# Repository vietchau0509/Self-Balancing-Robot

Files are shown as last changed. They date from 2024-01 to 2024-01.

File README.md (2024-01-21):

# Self-Balancing-Robot
This project involves designing a 2-wheeled, self-balancing robot with capabilities for sensor integration. Using 3-axis accelerometers, gyros, and odometry, the robot maintains an upright position while allowing for IR remote-controlled movement.

Key Components

3D-Printed Robot Frame: Forms the robot's structural base.

Robot Wheels (2): Enable robot mobility.

Training Stand: Assists in testing and development.

Buna-N Nitrile O-Rings (2): Serve as mechanical buffers.

DC Gearhead Motors (2): Power the wheels.

Pan Head Screws (4): For component assembly.

DRV8833 Dual H-Bridge: Manages motor control.

MPU-6050 6-DOF IMU: Balancing and orientation data.

Optical Interrupters (2): Measure wheel rotation for odometry.

IR Sensor: Receives remote control signals.

Resistors (4): Limit current and provide pull-up for sensors.

Battery Holder: Contains batteries for power.

AA NiMH Batteries (4): Powers the robot without using alkaline batteries.

Double-Row Pin Headers (2): For component connections.

Single Pin Headers (2): For battery circuit connections.

Single-Row Socket Headers (2): Connects the motor driver.

Pitch Terminals (2): Facilitate wiring and connections.

Slide Switch: Manages battery circuit power.

Plastic-Thread Screws (6): Secures PCB and battery.

FR4 PC Board: Base for electronic components.

TM4C123G Eval Board: Central microcontroller.

IR Remote: Controls the robot remotely.

Dowel Rod: Structural element.

Top Weight: Balances and stabilizes the robot.

Development and Learning

This project demonstrates intricate hardware-software integration, offering a hands-on experience in robotic controls, sensor interfacing, and real-time system programming.

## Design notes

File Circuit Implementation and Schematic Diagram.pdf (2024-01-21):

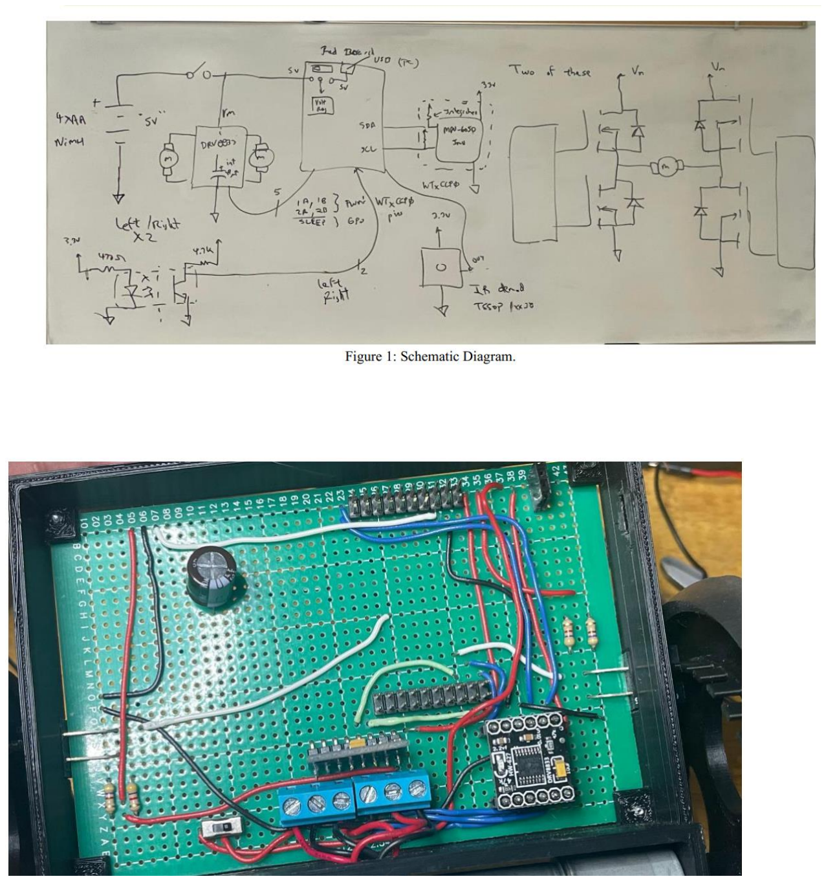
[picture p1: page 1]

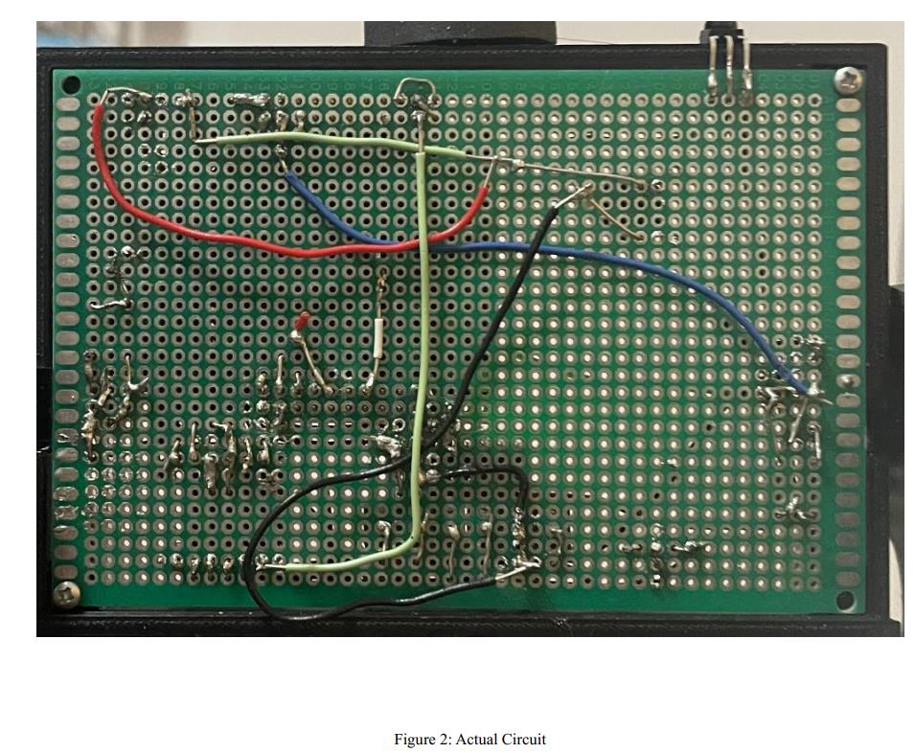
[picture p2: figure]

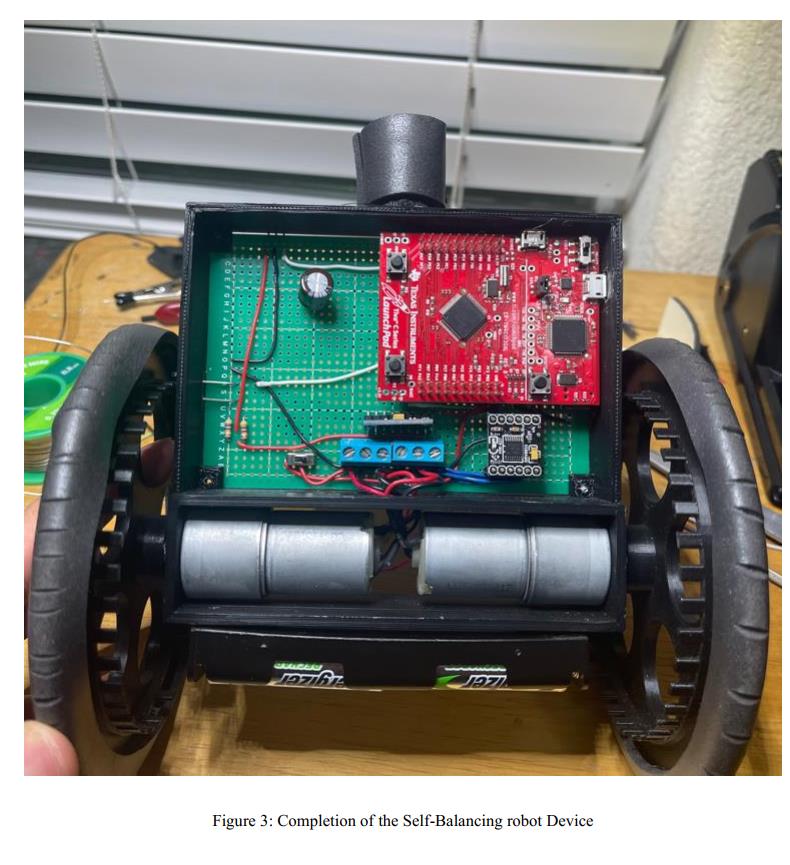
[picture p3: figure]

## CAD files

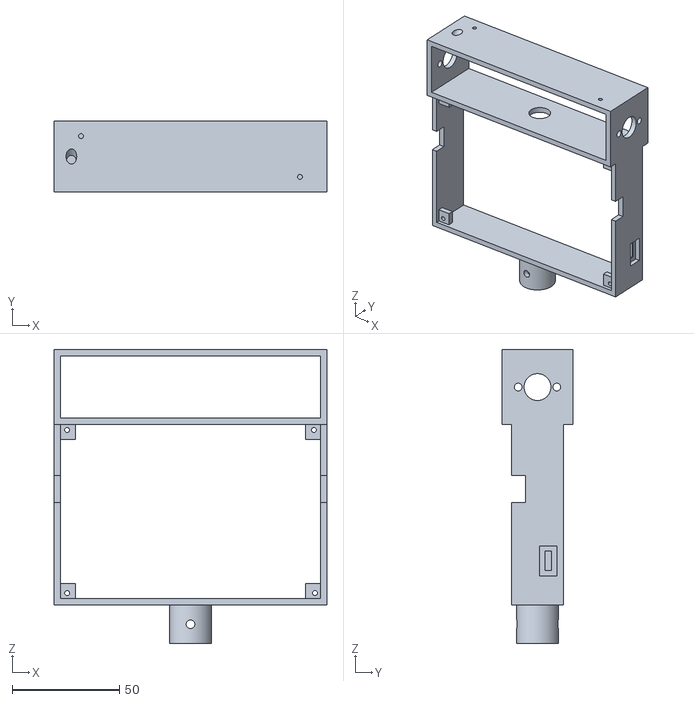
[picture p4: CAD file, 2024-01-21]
STL Files/2_wheel_robot_base.stl
127.0 x 33.0 x 137.0

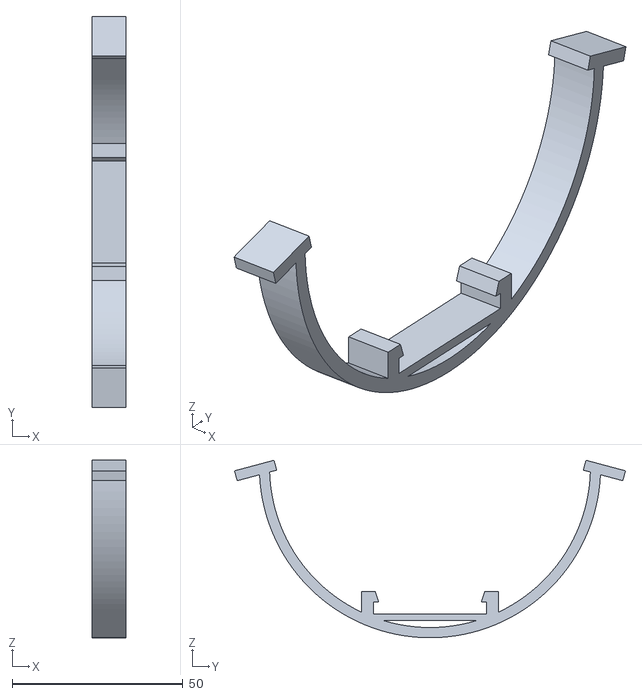
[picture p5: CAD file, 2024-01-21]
STL Files/stand.stl
10.0 x 114.6 x 52.0

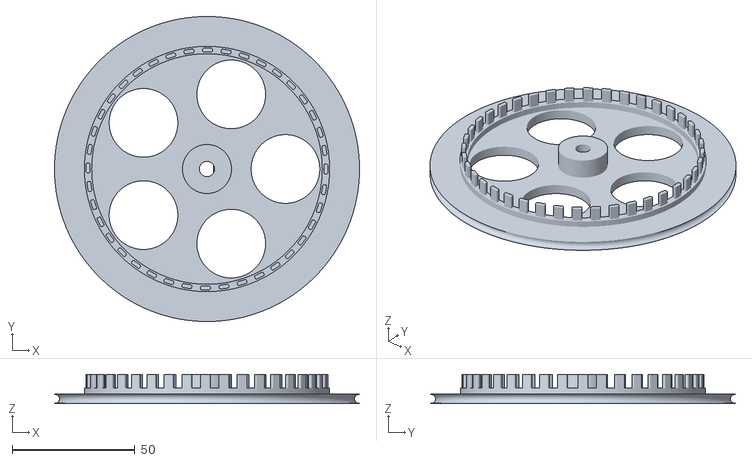
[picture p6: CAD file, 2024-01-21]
STL Files/125mm_wheel.stl
124.4 x 124.4 x 12.0

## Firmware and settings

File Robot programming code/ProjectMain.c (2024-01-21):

#include <stdint.h>
#include <stdbool.h>
#include <stdio.h>
#include <string.h>
#include "tm4c123gh6pm.h"
#include "gpio.h"
#include "clock.h"
#include "wait.h"
#include "nvic.h"
#include "uart0.h"
#include "motor_control.h"
#include "i2c0.h"
#include <math.h>  // for atan2 and sqrt
#include "eeprom.h"
#include <stdlib.h>


//IR Decoder PD0
//   PhA0 (PD6) and PhB0 (PD7) are connected to 256 cpr optical encoder
// Motor 0: PWM PA6, DIR PA7 --- OP sen PC7
// Motor 1: PWM PF2, DIR PF3 --- OP sen PC5

// Define the IR remote signals
const char RIGHT_ARROW[] =  "00100000110111110110000010011111";
const char LEFT_ARROW[] =   "00100000110111111110000000011111";
const char UP_ARROW[] =     "00100000110111110000001011111101";
const char DOWN_ARROW[] =   "00100000110111111000001001111101";
const char STOP[] =         "00100000110111110011111011000001";
#define SLEEP_PIN       PORTF, 1

#define IR_PIN          PORTD, 0
#define OP_PIN_PC5      PORTC, 5
#define OP_PIN_PC7      PORTC, 7



uint32_t targetinterruptCount_PC5 = 0;
uint32_t targetinterruptCount_PE2 = 0;
bool shouldStopMotors = false;
uint32_t OptTime0=0;
uint32_t OptTime1=0;
volatile uint32_t OptCount0=0;
volatile uint32_t OptCount1=0;
// Struct to represent the IR protocol parameters
typedef struct
{
    uint32_t InitTime;
    uint32_t Logic_0;
    uint32_t Logic_1;
    uint32_t Leniency;
} IRProtocol;

// Enum to represent the different buttons on the remote
typedef enum
{
    BUTTON_RIGHT_ARROW,
    BUTTON_LEFT_ARROW,
    BUTTON_UP_ARROW,
    BUTTON_DOWN_ARROW,
    BUTTON_STOP,
    BUTTON_UNKNOWN,

} RemoteButton;

// Struct to represent the IR signal data
typedef struct
{
    char data[33]; // 33 to include null terminator
    uint32_t count;
    bool ReceivingBit_Flag;
    RemoteButton button;
} IRSignal;

// Initialize the IR protocol parameters
const IRProtocol irProtocol = {
                               .InitTime = 13500000, // Start signal duration ns
                               .Logic_0 = 1125000,      // '0' signal duration --2T
                               .Logic_1 = 2250000,      // '1' signal duration -- 4T
                               .Leniency = (2250000/4)*0.5        // Tolerance for timing discrepancies 0.5T
};

// Initialize the IR signal
IRSignal irSignal = {
                     .data = {0},
                     .count = 0,
                     .ReceivingBit_Flag = false,
                     .button = BUTTON_UNKNOWN
};


void initHw()
{
    // System clock to 40 MHz
    initSystemClockTo40Mhz();
    // Enable Wide Timer 0,1,2
    SYSCTL_RCGCWTIMER_R |= SYSCTL_RCGCWTIMER_R2| SYSCTL_RCGCWTIMER_R0| SYSCTL_RCGCWTIMER_R1 |SYSCTL_RCGCWTIMER_R3;

    _delay_cycles(3);
    // Enable ports
    enablePort(PORTD);
    enablePort(PORTF);
    enablePort(PORTC);


    //**************************Remote DCD**********************************
    // Configure IR pin DCD
    setPinAuxFunction(IR_PIN, GPIO_PCTL_PD0_WT2CCP0);
    selectPinDigitalInput(IR_PIN);

    //**************************OPB876N55***********************************
    // Configure IR pin OPB876N55 optical PortC pin 5
    setPinAuxFunction(OP_PIN_PC5, GPIO_PCTL_PC5_WT0CCP1);
    selectPinDigitalInput(OP_PIN_PC5);

    // Configure IR pin OPB876N55 optical PortC pin 7
    setPinAuxFunction(OP_PIN_PC7, GPIO_PCTL_PC7_WT1CCP1);
    selectPinDigitalInput(OP_PIN_PC7);
    //**********************************************************************

    selectPinPushPullOutput(SLEEP_PIN);

}


//**************************MPU6050 I2C*******************************************
// MPU-6050 I2C Address and Registers
#define MPU6050_ADDRESS     0x68
#define MPU6050_PWR_MGMT_1  0x6B
#define MPU6050_WHO_AM_I    0x75
#define MPU6050_ACCEL_XOUT_H 0x3B
#define MPU6050_GYRO_XOUT_H  0x43
int16_t gyroBias[3] = {0, 0, 0};
float initialPitch = 0;
float initialtilt = 90.0f;

void initMPU6050() {
    writeI2c0Register(MPU6050_ADDRESS, MPU6050_PWR_MGMT_1, 0x00);
}

void readMpu6050Data(int16_t* accelData, int16_t* gyroData) {
    uint8_t buffer[14];
    readI2c0Registers(MPU6050_ADDRESS, MPU6050_ACCEL_XOUT_H, buffer, 14);
    int i;
    for (i = 0; i < 3; i++) {
        accelData[i] = (int16_t)(buffer[2*i] << 8 | buffer[2*i + 1]);
        gyroData[i] = (int16_t)(buffer[2*i + 8] << 8 | buffer[2*i + 9]);
    }
}

void calibrateGyroscope() {
    int numReadings = 1000;
    int16_t gyroData[3];
    int16_t accelData[3];
    int i;
    for (i = 0; i < numReadings; i++) {
        readMpu6050Data(accelData, gyroData);
        gyroBias[0] += gyroData[0];
        gyroBias[1] += gyroData[1];
        gyroBias[2] += gyroData[2];
        waitMicrosecond(1000);
    }

    gyroBias[0] /= numReadings;
    gyroBias[1] /= numReadings;
    gyroBias[2] /= numReadings;

    float ax = accelData[0] / 16384.0;
    float ay = accelData[1] / 16384.0;
    float az = accelData[2] / 16384.0;

    initialPitch = atan2(ay, sqrt(ax * ax + az * az)) * 180.0 / M_PI;
    // tilt is set to 90 degrees above
}

char* itoa(int value, char* result, int base) {
    if (base < 2 || base > 36) {
        *result = '\0';
        return result;
    }

    char* ptr = result, *ptr1 = result, tmp_char;
    int tmp_value;
    do {
        tmp_value = value;
        value /= base;
        *ptr++ = "zyxwvutsrqponmlkjihgfedcba9876543210123456789abcdefghijklmnopqrstuvwxyz"[35 + (tmp_value - value * base)];
    } while (value);
    if (tmp_value < 0 && base == 10)
        *ptr++ = '-';
    *ptr-- = '\0';
    while (ptr1 < ptr) {
        tmp_char = *ptr;
        *ptr-- = *ptr1;
        *ptr1++ = tmp_char;
    }
    return result;
}


void CountOptical_PC7_L(void)
{

    OptTime0= WTIMER1_TBV_R /40;
    WTIMER1_TBV_R =0; // reset value of widetimer 1 counter
    WTIMER1_ICR_R = TIMER_ICR_CBECINT;

}
void CountOptical_PC5_R(void)
{

    OptTime1= WTIMER0_TBV_R /40 ;
    WTIMER0_TBV_R =0; // reset value of widetimer 1 counter
    WTIMER0_ICR_R = TIMER_ICR_CBECINT;
}


void GPIOPortC_Handler(void)
{
    // Read the raw interrupt status to identify which pin(s) caused the interrupt
    uint32_t status = GPIO_PORTC_RIS_R; // This contains the raw interrupt status

    // Check if PC5 caused the interrupt
    if (status & (1 << 5))
    {
        // Handle the interrupt for PC5 (e.g., increase counter, toggle LED, etc.)
        OptCount1++;

        // Clear the interrupt for PC5
        GPIO_PORTC_ICR_R = (1 << 5);
    }

    // Check if PC5 caused the interrupt
    if (status & (1 << 7))
    {
        // Handle the interrupt for PC5 (e.g., increase counter, toggle LED, etc.)
        OptCount0++;

        // Clear the interrupt for PC5
        GPIO_PORTC_ICR_R = (1 << 7);
    }
}

//******************** DECODER *******************************************************
void enableWideTimer_DCD()
{
    WTIMER2_CTL_R &= ~TIMER_CTL_TAEN;
    WTIMER2_CFG_R = 4;
    WTIMER2_TAMR_R = TIMER_TAMR_TACMR | TIMER_TAMR_TAMR_CAP | TIMER_TAMR_TACDIR;
    WTIMER2_CTL_R = TIMER_CTL_TAEVENT_NEG;
    WTIMER2_TAV_R = 0;
    WTIMER2_CTL_R |= TIMER_CTL_TAEN;


}

void SetUp_Interrupt()
{
    //DCD
    enablePort(PORTD);
    selectPinInterruptFallingEdge(IR_PIN);

    //OPTICAL
    //enablePort(PORTE);
    enablePort(PORTC);
    enablePinInterrupt(OP_PIN_PC7);
    selectPinInterruptRisingEdge(OP_PIN_PC7);
    enableNvicInterrupt(INT_GPIOC);


    enablePort(PORTC);
    enablePinInterrupt(OP_PIN_PC5);
    selectPinInterruptRisingEdge(OP_PIN_PC5);
    enableNvicInterrupt(INT_GPIOC);





}

void DECODE_ISR()
{
    uint32_t time = 0;
    enableWideTimer_DCD();
    time = WTIMER2_TAR_R * 25;  // convert ns

    if (time >= irProtocol.InitTime - irProtocol.Leniency && time <= irProtocol.InitTime + irProtocol.Leniency)
    {
        irSignal.ReceivingBit_Flag = true;
        irSignal.count = 0;
    }

    if (irSignal.ReceivingBit_Flag)
    {
        if (time >= irProtocol.Logic_0 - irProtocol.Leniency && time <= irProtocol.Logic_0 + irProtocol.Leniency)
        {
            irSignal.data[irSignal.count] = '0';
            irSignal.count++;
        } else if (time >= irProtocol.Logic_1 - irProtocol.Leniency && time <= irProtocol.Logic_1 + irProtocol.Leniency) {
            irSignal.data[irSignal.count] = '1';           irSignal.count++;
        }

        if (irSignal.count >= 32)
        {
            irSignal.ReceivingBit_Flag = false;
            irSignal.data[irSignal.count] = '\0';  // Null-terminate the string

            // Output the received data string over UART for debugging
            char debugString[50];
            snprintf(debugString, sizeof(debugString), "data = %s \n", irSignal.data);
            putsUart0(debugString);


            if (strcmp(irSignal.data, RIGHT_ARROW) == 0)
            {
                irSignal.button = BUTTON_RIGHT_ARROW;
            }
            else if (strcmp(irSignal.data, LEFT_ARROW) == 0)
            {
                irSignal.button = BUTTON_LEFT_ARROW;
            }
            else if (strcmp(irSignal.data, UP_ARROW) == 0)
            {
                irSignal.button = BUTTON_UP_ARROW;
            }
            else if (strcmp(irSignal.data, DOWN_ARROW) == 0)
            {
                irSignal.button = BUTTON_DOWN_ARROW;
            }

            else if (strcmp(irSignal.data, STOP) == 0)
            {
                irSignal.button = BUTTON_STOP;
            }

            else
            {
                irSignal.button = BUTTON_UNKNOWN;
            }
        }
    }

    clearPinInterrupt(IR_PIN);
}

//*******************GPIOC_OPB876N55 SENSOR**********************************

void enableWTimerMode(uint8_t num)
{
    switch (num)
    {
    case 0:
        WTIMER0_CTL_R &= ~TIMER_CTL_TBEN;               // Turn off counter before reconfiguring
        WTIMER0_CFG_R = 4;                              // Configures as 32-bit counter (A only)
        WTIMER0_TBMR_R = TIMER_TBMR_TBCMR | TIMER_TBMR_TBMR_CAP | TIMER_TBMR_TBCDIR;
        // Configure for edge time mode, count up
        WTIMER0_CTL_R = TIMER_CTL_TBEVENT_POS;          // Measure time from negative edge to negative edge
        WTIMER0_IMR_R = TIMER_IMR_CBEIM;
        WTIMER0_TBV_R = 0;                              // Reset counter for first period
        WTIMER0_CTL_R |= TIMER_CTL_TBEN;                // Turn on counter
        enableNvicInterrupt(INT_WTIMER0B);
        break;

    case 1:
        WTIMER1_CTL_R &= ~TIMER_CTL_TBEN;               // Turn off counter before reconfiguring
        WTIMER1_CFG_R = 4;                              // Configures as 32-bit counter (A only)
        WTIMER1_TBMR_R = TIMER_TBMR_TBCMR | TIMER_TBMR_TBMR_CAP | TIMER_TBMR_TBCDIR;
        // Configure for edge time mode, count up
        WTIMER1_CTL_R = TIMER_CTL_TBEVENT_POS;          // Measure time from negative edge to negative edge
        WTIMER1_IMR_R = TIMER_IMR_CBEIM;
        WTIMER1_TBV_R = 0;                              // Reset counter for first period
        WTIMER1_CTL_R |= TIMER_CTL_TBEN;                // Turn on counter
        enableNvicInterrupt(INT_WTIMER1B);
        break;
    case 2:
        //configuration  (WTIMER3A)
        WTIMER3_CTL_R &= ~TIMER_CTL_TAEN;
        WTIMER3_CFG_R = 4;
        WTIMER3_TAMR_R = TIMER_TAMR_TACMR | TIMER_TAMR_TAMR_CAP | TIMER_TAMR_TACDIR;
        WTIMER3_CTL_R = TIMER_CTL_TAEVENT_POS;
        WTIMER3_IMR_R = TIMER_IMR_CAEIM;
        WTIMER3_TAV_R = 0;
        WTIMER3_CTL_R |= TIMER_CTL_TAEN;
        NVIC_EN3_R = 1 << (INT_WTIMER3A-16-96);
        break;
    }
}

void disableWTimerMode(uint8_t num)
{
    switch (num)
    {
    case 0:
        WTIMER0_CTL_R &= ~TIMER_CTL_TBEN;               // Turn off counter
        disableNvicInterrupt(INT_WTIMER0B);
        break;
    case 1:
        WTIMER1_CTL_R &= ~TIMER_CTL_TBEN;               // Turn off counter
        disableNvicInterrupt(INT_WTIMER1B);
        break;
    case 2:
        //configuration for channel 3 (WTIMER3)
        WTIMER3_CTL_R &= ~TIMER_CTL_TAEN;
        NVIC_DIS3_R = 1 << (INT_WTIMER3A-16-96);
        break;

    }
}

//**************************************EM1***************************************

#define NUMBER_OF_EVENTS 1
bool timeMode = false;
uint32_t frequency = 0;
uint32_t time = 0;
uint32_t time1 = 0;
uint32_t time2 = 0;
uint32_t time3 = 0;

#define MAX_CHARS 80
#define MAX_FIELDS 6

typedef struct USER_DATA
{
    char buffer[MAX_CHARS + 1];
    uint8_t fieldCount;
    uint8_t fieldPosition[MAX_FIELDS];
    char fieldType[MAX_FIELDS];
}
USER_DATA;



typedef struct EVENT_DATA
{
    int angle;
    int distance;


} EVENT_DATA;

EVENT_DATA events[NUMBER_OF_EVENTS];




void getsUart0(USER_DATA *data)
{
    uint8_t count = 0;
    char c = NULL;

    while (true)
    {
        c = getcUart0();

        if ((c == 8 || c == 127) && count > 0)
        {
            count--;
        }
        else if (c == 13)
        {
            data->buffer[count] = '\0';
            return;
        }
        else if (c >= 32)
        {
            data->buffer[count] = c;
            count++;
        }

        if (count == MAX_CHARS)
        {
            data->buffer[count] = '\0';
            return;
        }
    }
}
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
int main(void)
    {


    waitMicrosecond(1000000);
    initHw();
    initUart0();
    setUart0BaudRate(115200, 40e6);
    SetUp_Interrupt();
    initMotorControl();
    initI2c0();
    initMPU6050();
    initEeprom();
    float distanceTraveled=0;

    // Enable interrupts for GPIO Port C & D
    enablePinInterrupt(IR_PIN);
    enableNvicInterrupt(INT_GPIOD);

    RemoteButton lastButton = BUTTON_UNKNOWN; // To track the last button state

    // Setup UART0 baud rate
    setUart0BaudRate(115200, 40e6);


    // Load the event data from EEPROM
    loadDeviceParameters(events, NUMBER_OF_EVENTS);

    USER_DATA data;

    while (1)
    {


        bool inputReceived = false;

        int16_t accelData[3];
        int16_t gyroData[3];
        readMpu6050Data(accelData, gyroData);

        float ax = accelData[0] / 16384.0;
        //        float ay = accelData[1] / 16384.0;
        float az = accelData[2] / 16384.0;

        float tilt = atan2(-ax, az) * 180.0 / M_PI + initialtilt;

        enableWTimerMode(0);
        enableWTimerMode(1);
        enableWTimerMode(2);


        while (time3 < 10000000)
        {
            time3 = WTIMER3_TAV_R/40;
            if (kbhitUart0())
            {
                inputReceived = true;
                break;
            }

        }

        disableWTimerMode(2);

        if (!inputReceived)
        {

            if (irSignal.button != lastButton)
            {
                switch (irSignal.button)
                {


                case BUTTON_UP_ARROW:
                {

                    BWD = false;
                    FWD=false;

                    setInitialZAxisAngle();
                    calibrateGyro();
                    FWD = true; // Start moving forward
                    setPinValue(SLEEP_PIN, 1);
                    OptCount0 = 0;
                    OptCount1 = 0;
                    int F=1;
                    if(FWD==true && F==1)
                    {
                        setPinValue(SLEEP_PIN, 1);
                        setMotor(0, 780, 0);
                        setMotor(1, 520, 1);
                        waitMicrosecond(7000);
                        setMotor(0, 0, 0);
                        setMotor(1, 0, 0);

                        F =0;
                    }

                    if (FWD == true)
                    {
                        MAX_TILT_ANGLE = 60.0;
                    }

                    while (FWD==true)
                    {

                        distanceTraveled = (OptCount0 * distancePerTooth);


                        setPinValue(SLEEP_PIN, 1);

                        goStraightWithBalance();
                        if(distanceTraveled>=targetDistance)
                        {

                            BWD = false;
                            FWD=false;
                            OptCount0 = 0;
                            OptCount1 = 0;
                            setPinValue(SLEEP_PIN, 0);
                            setMotor(0, 0, 0);
                            setMotor(1, 0, 0);
                            waitMicrosecond(150000);

                        }


                    }



                    break;
                }



                case BUTTON_DOWN_ARROW: // Backward
                {
                    BWD = false;
                    FWD=false;
                    setInitialZAxisAngle();
                    calibrateGyro();
                    BWD = true; // Start moving forward
                    setPinValue(SLEEP_PIN, 1);
                    OptCount0 = 0;
                    OptCount1 = 0;

                    int F=1;
                    if(FWD==true && F==1)
                    {
                        setPinValue(SLEEP_PIN, 1);
                        setMotor(0, 520, 0);
                        setMotor(1, 780, 1);
                        waitMicrosecond(7000);
                        setMotor(0, 0, 0);
                        setMotor(1, 0, 0);

                        F =0;
                    }

                    if (BWD == true)
                    {
                        MAX_TILT_ANGLE = 120.0;
                    }

                    while (BWD==true)
                    {

                        distanceTraveled = (OptCount0* distancePerTooth);
                        setPinValue(SLEEP_PIN, 1);
                        goStraightWithBalance();

                        if(distanceTraveled>=targetDistance)
                        {


                            BWD = false;
                            FWD=false;
                            OptCount0 = 0;
                            OptCount1 = 0;
                            setPinValue(SLEEP_PIN, 0);
                            setMotor(0, 0, 0);
                            setMotor(1, 0, 0);
                            waitMicrosecond(150000);


                        }


                    }
                }

                break;

                case BUTTON_LEFT_ARROW:
                    CW=false;
                    CCW=true;
                    setPinValue(SLEEP_PIN, 1);
                    turnDegrees(abs(events[0].angle));
                    waitMicrosecond(1000);
                    CW=false;
                    CCW=false;
                    break;

                case BUTTON_RIGHT_ARROW:

                    CCW=false;
                    CW=true;
                    setPinValue(SLEEP_PIN, 1);
                    turnDegrees(abs(events[0].angle));
                    waitMicrosecond(1000);
                    CW=false;
                    CCW=false;
                    break;


                case BUTTON_STOP:
                    OptCount0=0;
                    OptCount1=0;
                    setMotor(0, 0, 0);
                    setMotor(1, 0, 0);

                    waitMicrosecond(1000);

                    break;
                }

                lastButton = irSignal.button;  // Update lastButton after handling

                // If a button press was handled, reset to UNKNOWN for next detection
                if (irSignal.button != BUTTON_UNKNOWN)
                {

                    irSignal.button = BUTTON_UNKNOWN;
                }
            }



            waitMicrosecond(200);
            autobalance();

            continue;
        }



        // Get input from the user
        getsUart0(&data);

        // Parse the input
        parseFields(&data);

        // Handle the "event" command
        if (isCommand(&data, "reset", 0))
        {

            putsUart0("System is rebooting...\r\n");
            // Reset the microcontroller
            NVIC_APINT_R = NVIC_APINT_SYSRESETREQ;
            waitMicrosecond(1000000);
            putsUart0("=>System is successfully rebooted.\r\n");

        }

        else if (isCommand(&data, "set", 2) && strcmp(getFieldString(&data, 1), "angle") == 0)
        {
            int angle = getFieldInteger(&data, 2);
            events[0].angle = angle;
            saveDeviceParameters(events, NUMBER_OF_EVENTS);
            putsUart0("Angle set successfully.\r\n");

        }

        else if (isCommand(&data, "angle", 1) && strcmp(getFieldString(&data, 1), "clear") == 0)
        {
            clearAngle(events, 0, NUMBER_OF_EVENTS);
            saveDeviceParameters(events, NUMBER_OF_EVENTS);
            putsUart0("Angle cleared successfully.\r\n");
        }


        else if (isCommand(&data, "rotate", 1) && strcmp(getFieldString(&data, 1), "cw") == 0)
        {
            CW=true;
            CCW=false;
            setPinValue(SLEEP_PIN, 1);
            turnDegrees(abs(events[0].angle));
            waitMicrosecond(3000);
        }
        else if (isCommand(&data, "rotate", 1) && strcmp(getFieldString(&data, 1), "ccw") == 0)
        {
            CW=false;
            CCW=true;
            setPinValue(SLEEP_PIN, 1);
            turnDegrees(abs(events[0].angle));
            waitMicrosecond(3000);
        }



        else if (isCommand(&data, "angle", 0))
        {

            displayEvents(events, NUMBER_OF_EVENTS);
        }


        else if (isCommand(&data, "tilt", 0))
        {
            char str1[100];
            snprintf(str1, sizeof(str1), "Tilt=%.1f\n",tilt);
            putsUart0(str1);
        }


        else if (isCommand(&data, "forward", 0))
        {
            setInitialZAxisAngle();
            calibrateGyro();
            FWD = true; // Start moving forward
            setPinValue(SLEEP_PIN, 1);
            OptCount0 = 0;
            OptCount1 = 0;

            // Somewhere in your code where FWD and BWD are set
            if (FWD == true) {
                MAX_TILT_ANGLE = 80.0;
            } else if (BWD == true) {
                MAX_TILT_ANGLE = 130.0;
            }
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

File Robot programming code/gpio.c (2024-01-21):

// GPIO Library
// Jason Losh

//-----------------------------------------------------------------------------
// Hardware Target
//-----------------------------------------------------------------------------

// Target Platform: EK-TM4C123GXL with LCD/Keyboard Interface
// Target uC:       TM4C123GH6PM
// System Clock:    40 MHz

// Hardware configuration:
// GPIO APB ports A-F

//-----------------------------------------------------------------------------
// Device includes, defines, and assembler directives
//-----------------------------------------------------------------------------

#include <stdint.h>
#include <stdbool.h>
#include "tm4c123gh6pm.h"
#include "gpio.h"

// Bit offset of the registers relative to bit 0 of DATA_R at 3FCh
// reg offset x 4 bytes / reg x 8 bits / byte
#define OFS_DATA_TO_DIR    1*4*8
#define OFS_DATA_TO_IS     2*4*8
#define OFS_DATA_TO_IBE    3*4*8
#define OFS_DATA_TO_IEV    4*4*8
#define OFS_DATA_TO_IM     5*4*8
#define OFS_DATA_TO_IC     8*4*8
#define OFS_DATA_TO_AFSEL  9*4*8
#define OFS_DATA_TO_ODR   68*4*8
#define OFS_DATA_TO_PUR   69*4*8
#define OFS_DATA_TO_PDR   70*4*8
#define OFS_DATA_TO_DEN   72*4*8
#define OFS_DATA_TO_CR    74*4*8
#define OFS_DATA_TO_AMSEL 75*4*8

//-----------------------------------------------------------------------------
// Global variables
//-----------------------------------------------------------------------------

//-----------------------------------------------------------------------------
// Subroutines
//-----------------------------------------------------------------------------

void enablePort(PORT port)
{
    switch(port)
    {
        case PORTA:
            SYSCTL_RCGCGPIO_R |= SYSCTL_RCGCGPIO_R0;
            SYSCTL_GPIOHBCTL_R &= ~1;
            break;
        case PORTB:
            SYSCTL_RCGCGPIO_R |= SYSCTL_RCGCGPIO_R1;
            SYSCTL_GPIOHBCTL_R &= ~2;
            break;
        case PORTC:
            SYSCTL_RCGCGPIO_R |= SYSCTL_RCGCGPIO_R2;
            SYSCTL_GPIOHBCTL_R &= ~4;
            break;
        case PORTD:
            SYSCTL_RCGCGPIO_R |= SYSCTL_RCGCGPIO_R3;
            SYSCTL_GPIOHBCTL_R &= ~8;
            break;
        case PORTE:
            SYSCTL_RCGCGPIO_R |= SYSCTL_RCGCGPIO_R4;
            SYSCTL_GPIOHBCTL_R &= ~16;
            break;
        case PORTF:
            SYSCTL_RCGCGPIO_R |= SYSCTL_RCGCGPIO_R5;
            SYSCTL_GPIOHBCTL_R &= ~32;
    }
    _delay_cycles(3);
}

void disablePort(PORT port)
{
    switch(port)
    {
        case PORTA:
            SYSCTL_RCGCGPIO_R &= ~SYSCTL_RCGCGPIO_R0;
            break;
        case PORTB:
            SYSCTL_RCGCGPIO_R &= ~SYSCTL_RCGCGPIO_R1;
            break;
        case PORTC:
            SYSCTL_RCGCGPIO_R &= ~SYSCTL_RCGCGPIO_R2;
            break;
        case PORTD:
            SYSCTL_RCGCGPIO_R &= ~SYSCTL_RCGCGPIO_R3;
            break;
        case PORTE:
            SYSCTL_RCGCGPIO_R &= ~SYSCTL_RCGCGPIO_R4;
            break;
        case PORTF:
            SYSCTL_RCGCGPIO_R &= ~SYSCTL_RCGCGPIO_R5;
    }
    _delay_cycles(3);
}

void selectPinPushPullOutput(PORT port, uint8_t pin)
{
    uint32_t* p;
    p = (uint32_t*)port + pin + OFS_DATA_TO_ODR;
    *p = 0;
    p = (uint32_t*)port + pin + OFS_DATA_TO_DIR;
    *p = 1;
    p = (uint32_t*)port + pin + OFS_DATA_TO_DEN;
    *p = 1;
}

void selectPinOpenDrainOutput(PORT port, uint8_t pin)
{
    uint32_t* p;
    p = (uint32_t*)port + pin + OFS_DATA_TO_ODR;
    *p = 1;
    p = (uint32_t*)port + pin + OFS_DATA_TO_DIR;
    *p = 1;
    p = (uint32_t*)port + pin + OFS_DATA_TO_DEN;
    *p = 1;
}

void selectPinDigitalInput(PORT port, uint8_t pin)
{
    uint32_t* p;
    p = (uint32_t*)port + pin + OFS_DATA_TO_DIR;
    *p = 0;
    p = (uint32_t*)port + pin + OFS_DATA_TO_DEN;
    *p = 1;
    p = (uint32_t*)port + pin + OFS_DATA_TO_AMSEL;
    *p = 0;
}

void selectPinAnalogInput(PORT port, uint8_t pin)
{
    uint32_t* p;
    p = (uint32_t*)port + pin + OFS_DATA_TO_DEN;
    *p = 0;
    p = (uint32_t*)port + pin + OFS_DATA_TO_AMSEL;
    *p = 1;
    p = (uint32_t*)port + pin + OFS_DATA_TO_AFSEL;
    *p = 1;
}

void setPinCommitControl(PORT port, uint8_t pin)
{
    switch(port)
    {
        case PORTA:
            GPIO_PORTA_LOCK_R = GPIO_LOCK_KEY;
            break;
        case PORTB:
            GPIO_PORTB_LOCK_R = GPIO_LOCK_KEY;
            break;
        case PORTC:
            GPIO_PORTC_LOCK_R = GPIO_LOCK_KEY;
            break;
        case PORTD:
            GPIO_PORTD_LOCK_R = GPIO_LOCK_KEY;
            break;
        case PORTE:
            GPIO_PORTE_LOCK_R = GPIO_LOCK_KEY;
            break;
        case PORTF:
            GPIO_PORTF_LOCK_R = GPIO_LOCK_KEY;
    }
    uint32_t* p;
    p = (uint32_t*)port + pin + OFS_DATA_TO_CR;
    *p = 1;
}

void enablePinPullup(PORT port, uint8_t pin)
{
    uint32_t* p;
    p = (uint32_t*)port + pin + OFS_DATA_TO_PUR;
    *p = 1;
}
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

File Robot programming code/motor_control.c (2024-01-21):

// Motor Control Library

#include <stdint.h>
#include <stdbool.h>
#include "tm4c123gh6pm.h"
#include "motor_control.h"
#include "gpio.h"

// Bitband aliases
#define DIRECTION_F    (*((volatile uint32_t *)(0x42000000 + (0x400253FC-0x40000000)*32 + 3*4)))
#define DIRECTION_A    (*((volatile uint32_t *)(0x42000000 + (0x400043FC-0x40000000)*32 + 7*4)))
// Pins
#define PWM_PF PORTF,2
#define DIR_PF PORTF,3

#define PWM_PA PORTA,6
#define DIR_PA PORTA,7

//-----------------------------------------------------------------------------
// Subroutines
//-----------------------------------------------------------------------------

// Initialize motor control
void initMotorControl()
{
    // Enable clocks
    SYSCTL_RCGCPWM_R |= SYSCTL_RCGCPWM_R1;
    _delay_cycles(3);
    enablePort(PORTF);
    enablePort(PORTA);

    // Configure PWM_PA and DIRECTION outputs
    selectPinPushPullOutput(DIR_PA);
    selectPinPushPullOutput(PWM_PA);
    setPinAuxFunction(PWM_PA, GPIO_PCTL_PA6_M1PWM2);

    // Configure PWM_PF and DIRECTION outputs
    selectPinPushPullOutput(DIR_PF);
    selectPinPushPullOutput(PWM_PF);
    setPinAuxFunction(PWM_PF, GPIO_PCTL_PF2_M1PWM6);

    // Configure PWM module 1 to drive servo
    // PWM on M1PWM6 (PF2), M0PWM3a
    SYSCTL_SRPWM_R |= SYSCTL_SRPWM_R1;               // reset PWM1 module
    SYSCTL_SRPWM_R &= ~SYSCTL_SRPWM_R1;              // leave reset state
    _delay_cycles(3);                                // wait 3 clocks
    PWM1_1_CTL_R = 0;                                // turn-off PWM1 generator 1
    PWM1_1_GENA_R = PWM_1_GENA_ACTCMPAD_ONE | PWM_1_GENA_ACTLOAD_ZERO;
    PWM1_1_LOAD_R = 1024;                            // set period to 40 MHz sys clock / 2 / 1024 = 19.53125 kHz
    PWM1_1_CMPA_R = 0;                               // PWM off (0=always low, 1023=always high)
    PWM1_1_CTL_R = PWM_1_CTL_ENABLE;                 // turn-on PWM1 generator 3


    PWM1_3_CTL_R = 0;                                // turn-off PWM1 generator 3
    PWM1_3_GENA_R = PWM_1_GENA_ACTCMPAD_ONE | PWM_1_GENA_ACTLOAD_ZERO;
    PWM1_3_LOAD_R = 1024;                            // set period to 40 MHz sys clock / 2 / 1024 = 19.53125 kHz
    PWM1_3_CMPA_R = 0;                               // PWM off (0=always low, 1023=always high)
    PWM1_3_CTL_R = PWM_1_CTL_ENABLE;                 // turn-on PWM1 generator 3
    PWM1_ENABLE_R = PWM_ENABLE_PWM6EN | PWM_ENABLE_PWM2EN;               // enable PWM output


}
void setMotor(unsigned int n, unsigned int dutyCycle, bool dir)
{
    // Set the motor direction
    switch(n)
    {
        case 0:
            DIRECTION_A = dir;
            PWM1_1_CMPA_R = dutyCycle;
            break;
        case 1:
            DIRECTION_F = dir;
            PWM1_3_CMPA_R = dutyCycle;
            break;
    }
}
